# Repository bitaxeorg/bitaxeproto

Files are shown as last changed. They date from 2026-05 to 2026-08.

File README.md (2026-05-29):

bitaxeProto miner with quad Block Proto MC3 ASICs
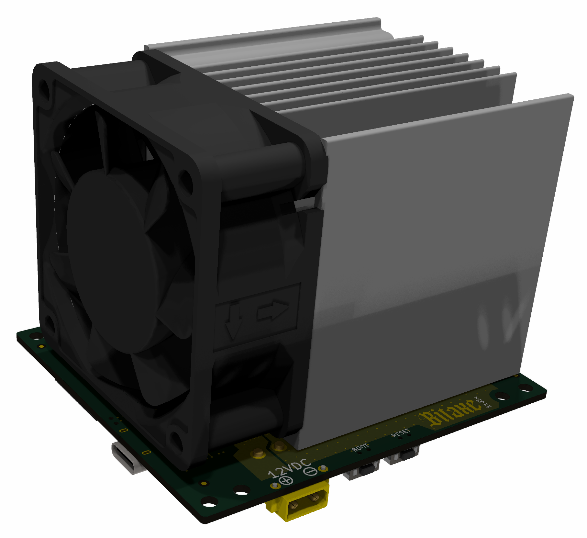
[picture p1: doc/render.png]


It is still an untested prototype! Don't build this expecting it to work yet.

- [Open Hardware License](LICENSE); Real Open Source.
	- [KiCAD](https://kicad.org) design files. 
- Four Proto MC3 ASICs, two stacks of two ASICs
	- Each MC3 is nominally 1.12V with approx 675 GH/s.
- 11-13V XT30 input voltage
- TPS546D24S single-phase voltage regulator tuned for 2.4V output @ 30A
	- The voltage regulator backside power plane is exposed to hopefully thermally bond it with the main heatsink.
- TPS546D24 backside busbar to cool the voltage regulator from the main heatsink.
- Fan controlled from the ESP32
- ESP32S3 for [esp-miner](https://github.com/bitaxeorg/esp-miner) support.
- Display moved off the main board. Should support the [bonanzaDisplay](https://github.com/bitaxeorg/bonanzadisplay)
- Gerbers _not_ provided to discourage side hacks and AliEx slop. HMU if you need help generating gerbers with KiCad.

©️ [bitaxeorg](https://bitaxe.org)

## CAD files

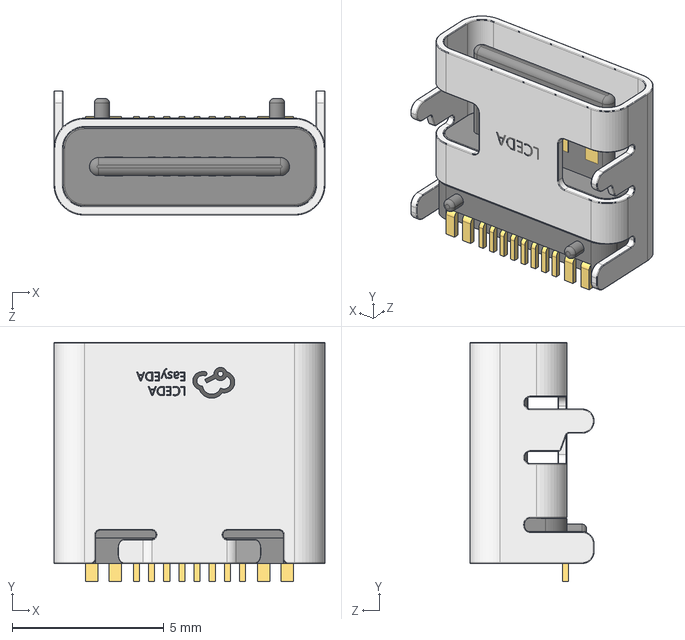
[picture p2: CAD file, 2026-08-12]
3d/USB-C_SMD-TYPE-C-31-M-12_1.step
8.94 x 7.90 x 4.10 mm

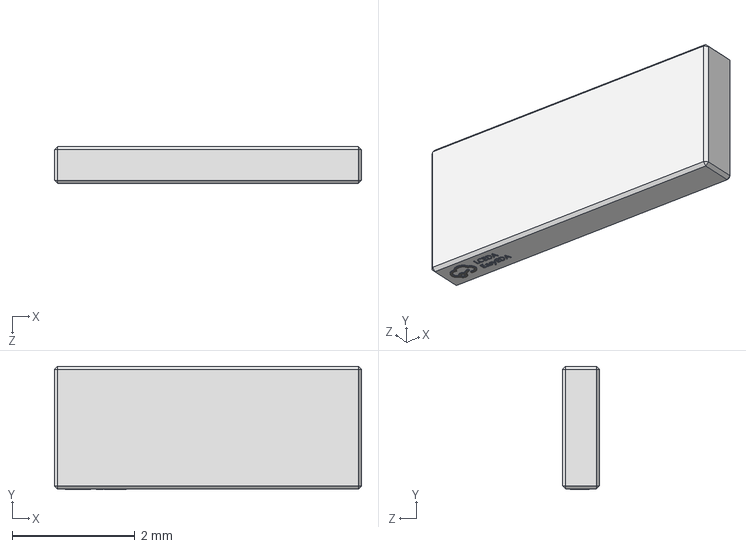
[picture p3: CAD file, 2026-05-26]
3dshapes/PAD-SMD_L5.0-W2.0_STHW4-DU-HN050206.step
5.00 x 2.01 x 0.6 mm

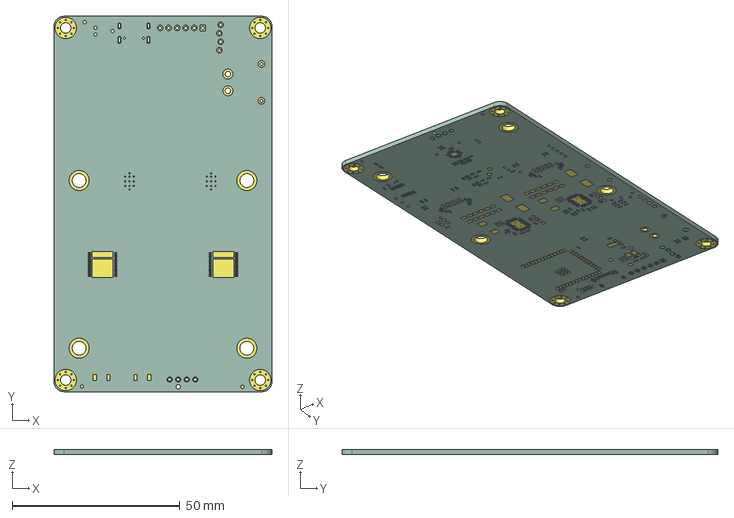
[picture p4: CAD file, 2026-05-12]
bitaxeProto.step
65.0 x 112.0 x 1.59 mm
BitaxeGT_pad
BitaxeGT_PCB

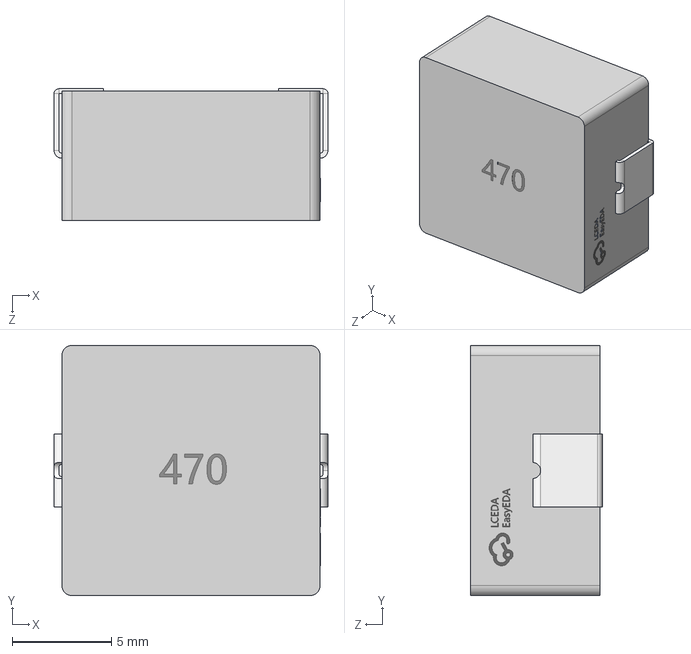
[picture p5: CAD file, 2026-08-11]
3d/IND-SMD_L13.8-W12.6-H6.5.step
13.8 x 12.6 x 6.63 mm

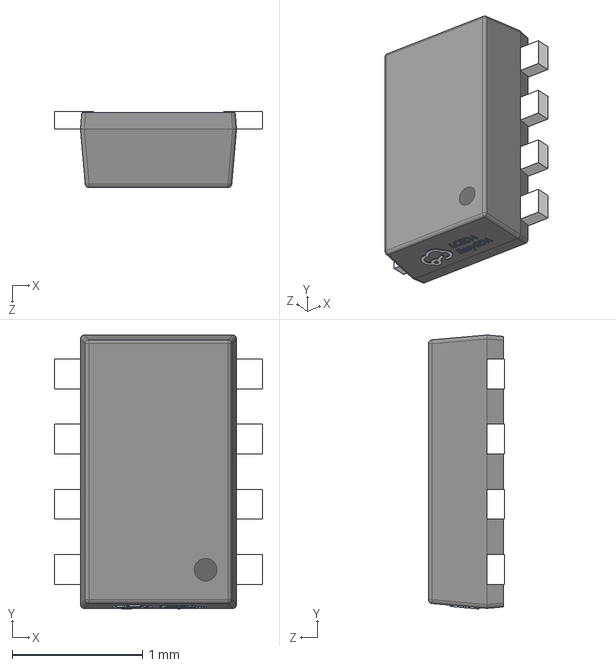
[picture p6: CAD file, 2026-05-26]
3dshapes/SOT-583-8_L2.1-W1.2-P0.50-LS1.6-BR.step
1.60 x 2.10 x 0.585 mm

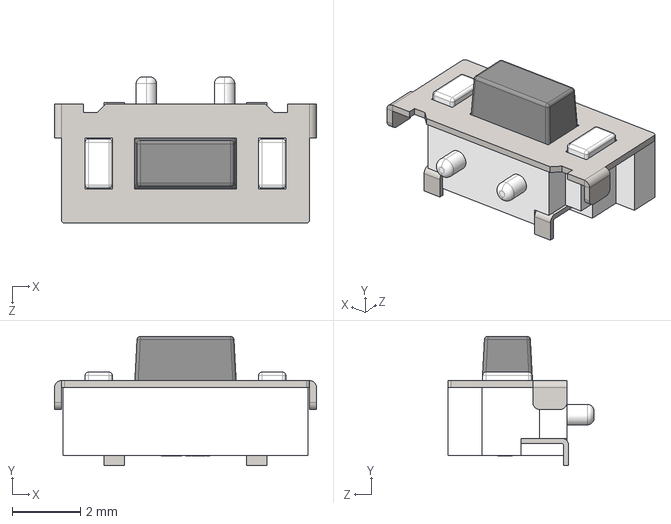
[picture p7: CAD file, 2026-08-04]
3d/SW-SMD_TC-S3601-3.5-260G-F0.6.step
7.70 x 3.80 x 4.30 mm

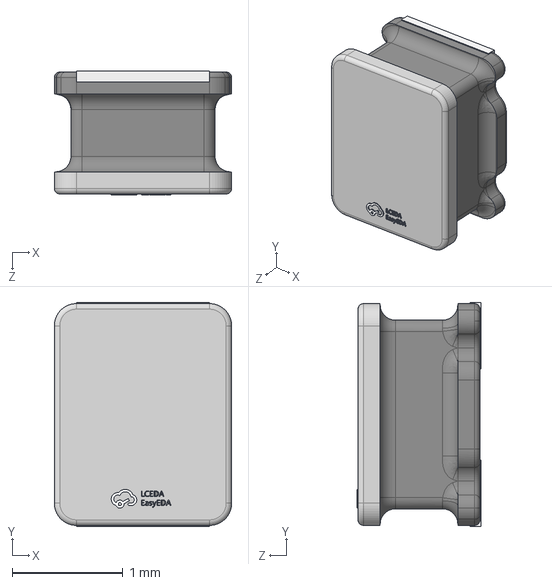
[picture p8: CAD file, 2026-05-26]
3dshapes/IND-SMD_L2.0-W1.6-H1.1.step
1.60 x 2.02 x 1.12 mm

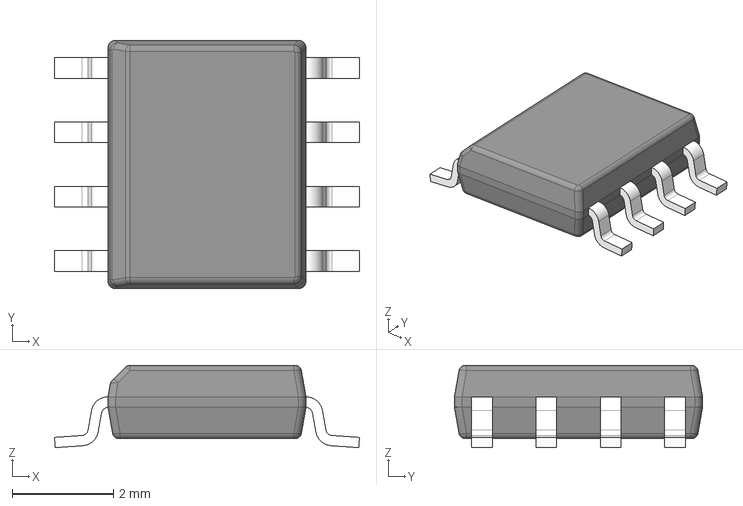
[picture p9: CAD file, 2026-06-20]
3d/D0008A.stp
6.02 x 4.90 x 1.63 mm
BODY-SO
LEAD-D0008A x 8

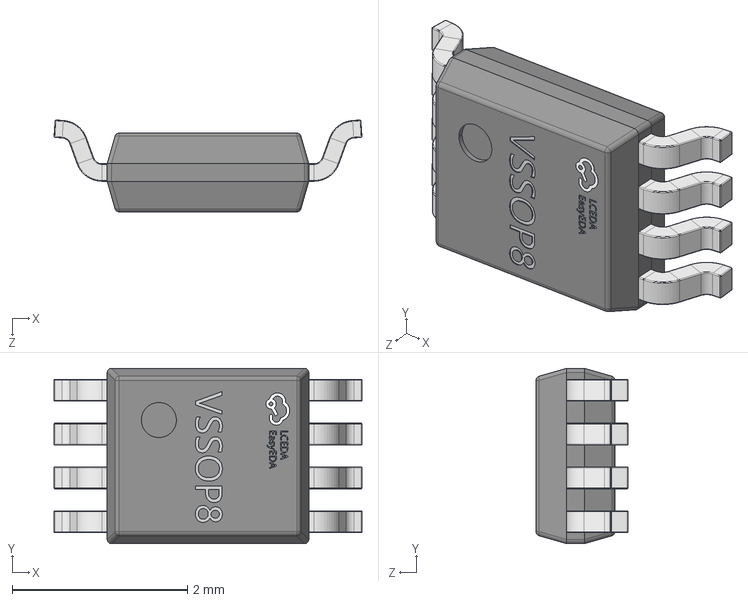
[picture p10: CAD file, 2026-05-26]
3dshapes/VSSOP-8_L2.0-W2.3-H0.9-LS3.1-P0.50.step
3.51 x 2.00 x 1.05 mm

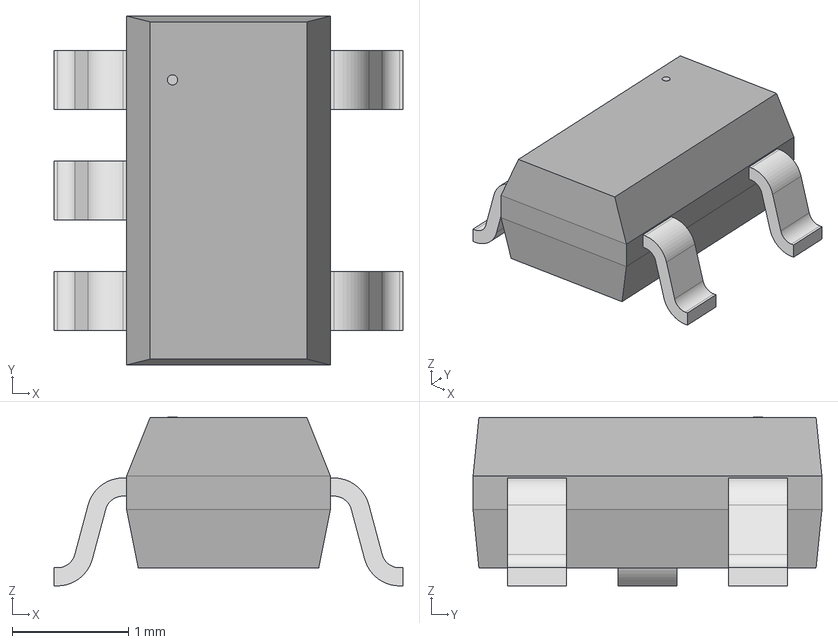
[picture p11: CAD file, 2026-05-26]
3d/SOT23-5_STM.step
3.00 x 3.00 x 1.45 mm

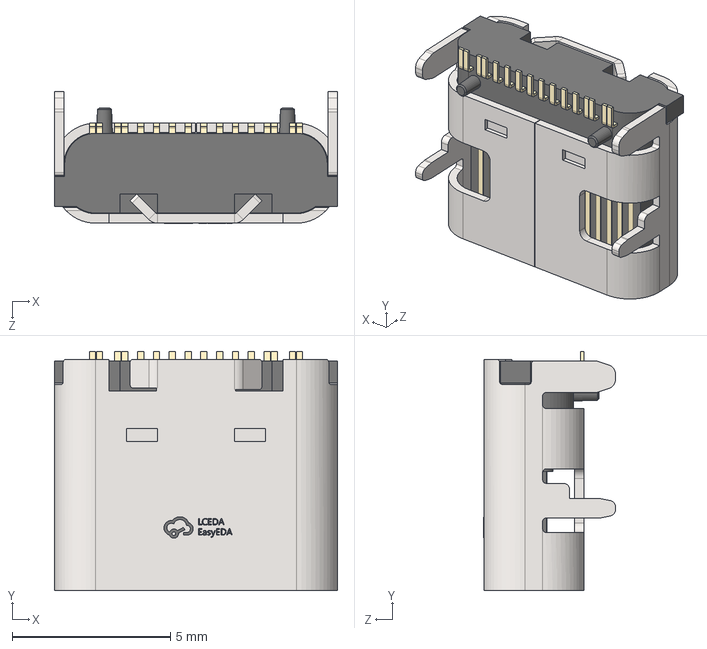
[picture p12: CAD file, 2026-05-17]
3dshapes/TYPE-C-SMD_SBC-160S1A-20-S412.step
8.94 x 7.55 x 4.17 mm

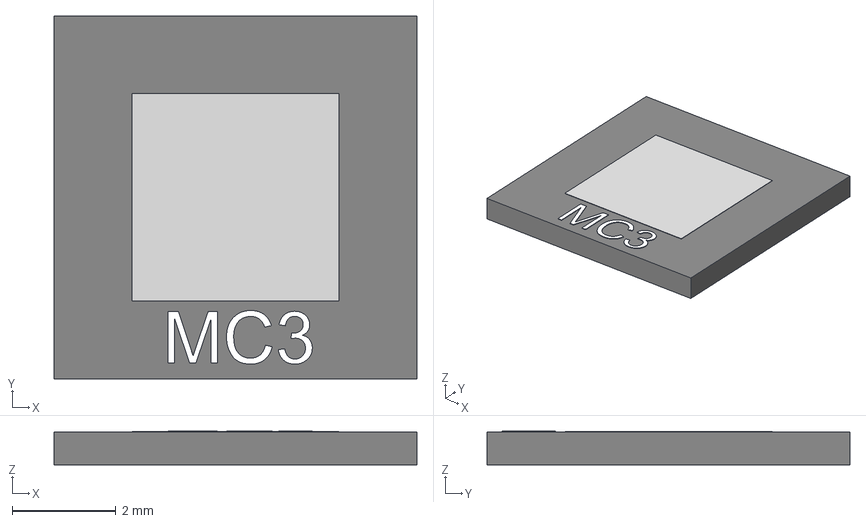
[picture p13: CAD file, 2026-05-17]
3d/mc3_model.step
7.00 x 7.00 x 0.655 mm

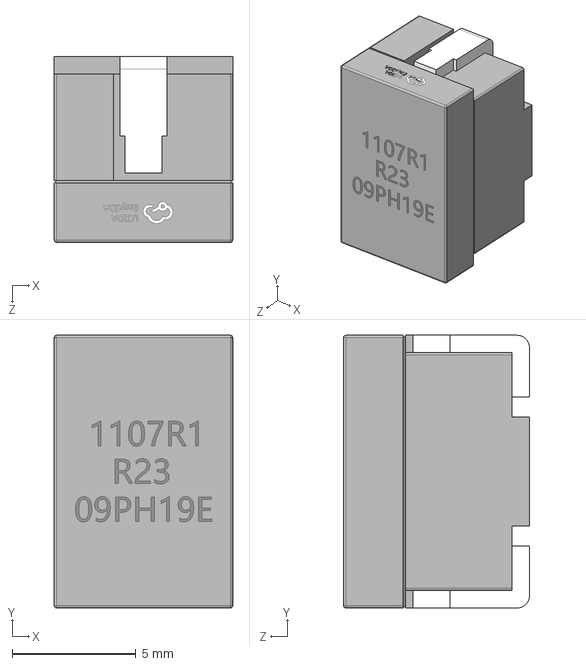
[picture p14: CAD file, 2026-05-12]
3dshapes/IND-SMD_L11.0-W7.2-H7.5.step
7.20 x 11.0 x 7.50 mm

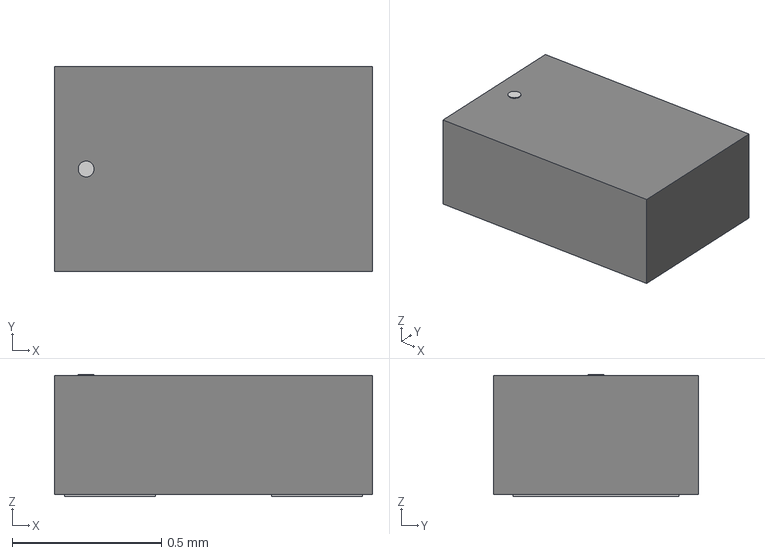
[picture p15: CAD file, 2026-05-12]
3d/DIODE_DLLFSD01LPH4-7B_DIO.step
1.07 x 0.686 x 0.409 mm

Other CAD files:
3d/DISST7789-176x320.STEP
3d/TXB0104RGYR.STEP
3d/ESP32-S3-WROOM-1-N8R2--3DModel-STEP-56544.STEP
3d/141_TL3330AFxxxQG.stp
3d/21-0164B_L622-1_MXM.step
3d/2R5TPE220MAFB.step
3d/470531000.stp
3d/54-00164.STEP
3d/BM04B-SRSS-TB.STEP
3d/BM1368xx.stp
3d/BQB0016A.stp
3d/BZM2.step
3d/BZM2model.step
3d/BitaxeGT_heatsink.step
3d/Bitaxe_Heatsink.step
3d/CS1213AG-tr.stp
3d/CUI_DEVICES_PJ-002AH.step
3d/CUI_DEVICES_PJ-036AH-SMT-TR.step
3d/CUI_DEVICES_PJ-037AH.step
3d/CX3225SB16000H0FLJCC.STEP
3d/Coilcraft-SLC1175.STEP
3d/Coilcraft-XAL1060.STEP
3d/Cree_PLCC6.stp
3d/Crystal_3225.step
3d/DCK0006A.stp
3d/DHVQFN14_SOT762-1_NEX.step
3d/DQG0008A.stp
3d/DQH0008A.stp
3d/DQN0004A.stp
3d/DRC0010J.stp
3d/DRL0006A.stp
3d/ECS-3225MV-500-CN-TR.STEP
3d/FFC2B35-08-T.STEP
3d/FP1006V2-R.STEP
3d/FPC-SMD_P0.50-8P_FGS-XJ-H2.0.step
3d/FTSH-105-01-F-DV-K.stp
3d/Fan 60x60x25mm.stp
3d/GT heatsink.step
3d/IHLP2020CZ.step
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

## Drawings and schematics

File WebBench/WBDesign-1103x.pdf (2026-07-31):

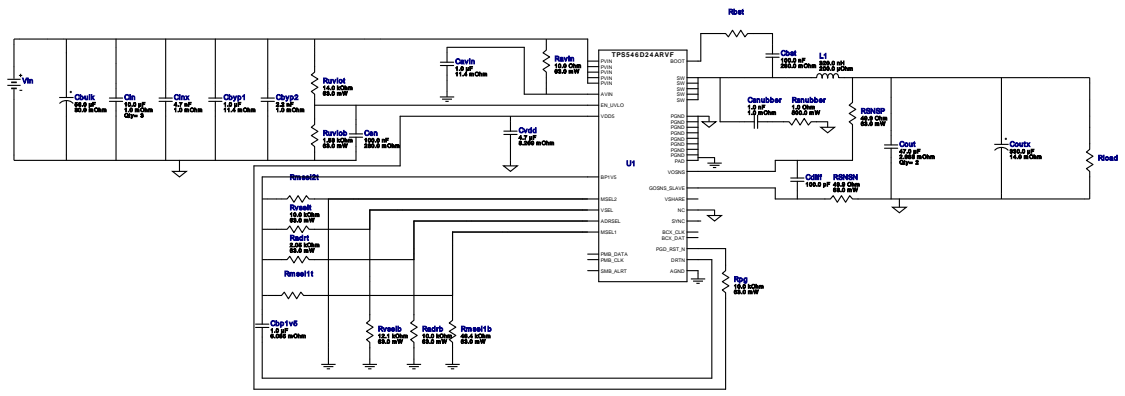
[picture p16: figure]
Cbyp2 2.2 nF 1.0 m Ohm; Cen 100.0 nF 280.0 m Ohm; Rsnubber 1.0 Ohm; Ruvlob 1.58 kOhm 63.0 m W; Cdiff 100.0 pF; Cavin 1.0 µF 11.4 m Ohm Ruvlot 14.0 kOhm; Coutx 330.0 µF 14.0 m Ohm; Cin 10.0 µF 1.0 m Ohm Qty= 3; RSNSN 49.9 Ohm 63.0 m W; Cout 47.0 µF; 2.988 m Ohm Qty= 2; RSNSP 49.9 Ohm 63.0 m W; Cinx 4.7 nF 1.0 m Ohm; Cbp1v5 1.0 µF 6.065 m Ohm; Cbyp1 1.0 µF 11.4 m Ohm; Rvselb 12.1 kOhm 63.0 m W; Rbst; Rpg 10.0 kOhm 63.0 m W; Ravin 10.0 Ohm 63.0 m W; Radrt 2.05 kOhm; Rm sel2t; Rvselt 10.0 kOhm; L1 320.0 nH 200.0 µOhm; Csnubber 1.0 nF; 1.0 m Ohm; Cbulk 56.0 µF 30.0 m Ohm; Cvdd 4.7 µF 8.209 m Ohm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

Copyright © 2026, Texas Instruments Incorporated | 1 | ti.com/webench

WEBENCH®
Design Report TPS546D24ARVFR : TPS546D24ARVFR 11V-13V to 2.20V @ 30A July 31, 2026 15:56:20 GMT-05:00

## WEBENCH ® Design Report

Design : 135 TPS546D24ARVFR
TPS546D24ARVFR 11V-13V to 2.20V @ 30A

VinMin = 11.0V
VinMax = 13.0V
Vout = 2.2V
Vout Sch = 2.2V
Iout = 30.0A

Device = TPS546D24ARVFR
Topology = Buck
Created = 2025-09-15 13:40:46.376 BOM Cost = $8.80
BOM Count = 31
Total Pd = 4.64W
1. Do not place Rmsel2t, Rmsel1t resistors. Place 0 Ohm resistor for Rbst.

### Design Alerts

TPS546D24A Design
The TPS546D24A is a PMBus(TM) device with key features listed below: PMBus(TM) features marked with * are included in WEBENCH(R) Power Designer. - Adaptive Voltage Scaling (AVS) through VOUT_COMMAND*, - Output voltage and current monitoring, - Thermal Shutdown,
- Programmable over current protection, - OCP,OV, UV, OT Levels, - Selectable Internal Compensation*, - Selectable Switching Frequency*,
- Turn-On and Turn-Off Delays, - UVLO*, Soft-Start*,OCP* and Soft-Stop. Use the Advanced Options on the left side to set the PMBus(TM) commands. Please refer to the TPS546D24A datasheet and visit http://www.ti.com/pmbus for more information.

## Electrical BOM

Name | Manufacturer | Part Number | Properties | Qty Price | Footprint
Cavin | TDK | C1005X5R1E105K050BC (https://product.tdk.com/ja/search/capacitor/ceramic/mlcc/info?part%5Fno%3DC1005X5R1E105K050BC) Series= X5R | Cap= 1.0 uF ESR= 11.4 mOhm VDC= 25.0 V IRMS= 0.0 A
1 | $0.02
| | | | | 0402 3 mm²
Cbp1v5 | MuRata | GRM188R60J105KA01D (http://psearch.en.murata.com/capacitor/result/smd/?status%3Dall%26pid%3DGRM188R60J105KA01D) Series= X5R

Cap= 1.0 uF
ESR= 6.065 mOhm
VDC= 6.3 V
IRMS= 1.36934 A

1 $0.01
0603 5 mm²
Cbst | AVX | 08053C104KAT2A (http://datasheets.avx.com/X7RDielectric.pdf) Series= X7R

Cap= 100.0 nF
ESR= 280.0 mOhm
VDC= 25.0 V
IRMS= 0.0 A

1 $0.01
0805 7 mm²

Design

Copyright © 2026, Texas Instruments Incorporated | 2 | ti.com/webench
Name | Manufacturer | Part Number | Properties | Qty Price | Footprint
Cbulk | Panasonic | 20SVPF56MX Series= SVPF | Cap= 56.0 uF ESR= 30.0 mOhm VDC= 20.0 V IRMS= 2.8 A
1 | $0.47
| | | | | CAPSMT_62_E61 53 mm²
Cbyp1 | TDK | C1005X5R1E105K050BC (https://product.tdk.com/ja/search/capacitor/ceramic/mlcc/info?part%5Fno%3DC1005X5R1E105K050BC) Series= X5R | Cap= 1.0 uF ESR= 11.4 mOhm VDC= 25.0 V IRMS= 0.0 A
1 | $0.02
| | | | | 0402 3 mm²
Cbyp2 | MuRata | GRM155R61E222KA01D (http://search.murata.co.jp/Ceramy/PnsearchViewAction.do) Series= X5R

Cap= 2.2 nF
ESR= 1.0 mOhm
VDC= 25.0 V
IRMS= 0.0 A

1 $0.01
0402 3 mm²
Cdiff | Yageo | CC0201JRNPO8BN101 (http://www.yageo.com/documents/recent/UPY%2DGP%5FNP0%5F16V%2Dto%2D50V%5F10.pdf) Series= C0G/NP0

Cap= 100.0 pF
VDC= 5.0 V
IRMS= 0.0 A

1 $0.01
0201 2 mm²
Cen | AVX | 08053C104KAT2A (http://datasheets.avx.com/X7RDielectric.pdf) Series= X7R

Cap= 100.0 nF
ESR= 280.0 mOhm
VDC= 25.0 V
IRMS= 0.0 A

1 $0.01
0805 7 mm²
Cin | TDK | C3225X7R1H106M250AC Series= X7R

Cap= 10.0 uF
ESR= 1.0 mOhm
VDC= 50.0 V
IRMS= 5.0 A

3 $0.27
1210 15 mm²
Cinx | MuRata | GRM155R71E472KA01D (http://search.murata.co.jp/Ceramy/PnsearchViewAction.do) Series= X7R

Cap= 4.7 nF
ESR= 1.0 mOhm
VDC= 25.0 V
IRMS= 0.0 A

1 $0.01
0402 3 mm²
Cout | Taiyo Yuden | MSASJ21GBB5476MTNA01 (https://ds.yuden.co.jp/TYCOMPAS/ut/detail?pn%3DMSASJ21GBB5476MTNA01%26u%3DM) Series= X5R

Cap= 47.0 uF
ESR= 2.988 mOhm
VDC= 6.3 V
IRMS= 3.5841 A

2 $0.09
0805 7 mm²
Coutx | Chemi-Con | APXE6R3ARA331MF80G (http://www.chemi%2Dcon.co.jp/cgi%2Dbin/CAT%5FDB/SEARCH/cat%5Fdb%5Fal.cgi?e%3De%26j%3Dp%26pdfname%3Dpxe) Series= PXE

Cap= 330.0 uF
ESR= 14.0 mOhm
VDC= 6.3 V
IRMS= 3.47 A

1 $0.93

CAPSMT_62_F80 74 mm²
Csnubber Yageo | CC0805KRX7R9BB102 (http://www.yageo.com/documents/recent/UPY%2DGPHC%5FX7R%5F6.3V%2Dto%2D50V%5F7.pdf)
| | Series= X7R
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

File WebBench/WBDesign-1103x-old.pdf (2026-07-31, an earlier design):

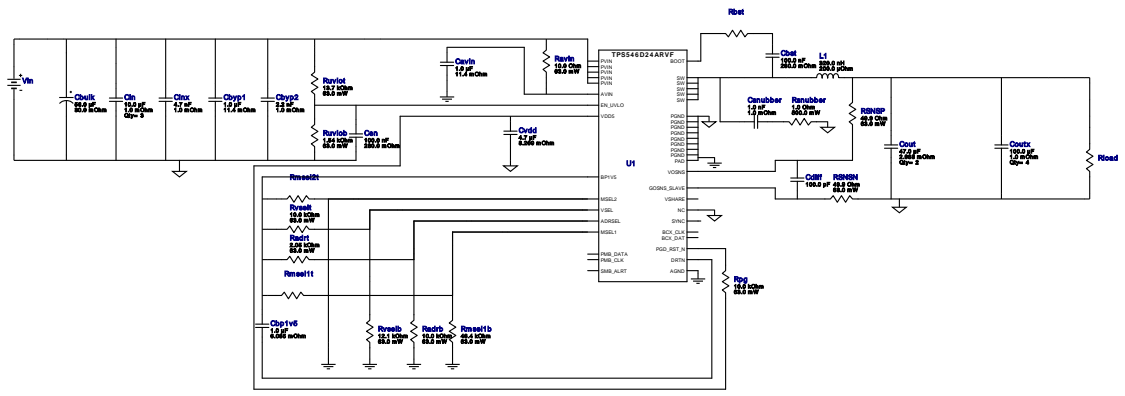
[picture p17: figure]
Cbyp2 2.2 nF 1.0 m Ohm; Cen 100.0 nF 280.0 m Ohm; Rsnubber 1.0 Ohm; Ruvlob 1.54 kOhm 63.0 m W; Cdiff 100.0 pF; Cavin 1.0 µF 11.4 m Ohm Ruvlot 13.7 kOhm; Coutx 100.0 µF 1.0 m Ohm Qty= 4; Cin 10.0 µF 1.0 m Ohm Qty= 3; RSNSN 49.9 Ohm 63.0 m W; Cout 47.0 µF; 2.988 m Ohm Qty= 2; RSNSP 49.9 Ohm 63.0 m W; Cinx 4.7 nF 1.0 m Ohm; Cbp1v5 1.0 µF 6.065 m Ohm; Cbyp1 1.0 µF 11.4 m Ohm; Rvselb 12.1 kOhm 63.0 m W; Rbst; Rpg 10.0 kOhm 63.0 m W; Ravin 10.0 Ohm 63.0 m W; Radrt 2.05 kOhm; Rm sel2t; Rvselt 10.0 kOhm; L1 320.0 nH 200.0 µOhm; Csnubber 1.0 nF; 1.0 m Ohm; Cbulk 56.0 µF 30.0 m Ohm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

Copyright © 2026, Texas Instruments Incorporated | 1 | ti.com/webench

WEBENCH®
Design Report TPS546D24ARVFR : TPS546D24ARVFR 11V-13V to 2.20V @ 30A July 20, 2026 19:36:30 GMT-05:00

## WEBENCH ® Design Report

Design : 134 TPS546D24ARVFR
TPS546D24ARVFR 11V-13V to 2.20V @ 30A

VinMin = 11.0V
VinMax = 13.0V
Vout = 2.2V
Vout Sch = 2.2V
Iout = 30.0A

Device = TPS546D24ARVFR
Topology = Buck
Created = 2025-09-15 13:40:46.376 BOM Cost = $8.55
BOM Count = 34
Total Pd = 4.63W
1. Do not place Rmsel2t, Rmsel1t resistors. Place 0 Ohm resistor for Rbst.

### Design Alerts

TPS546D24A Design
The TPS546D24A is a PMBus(TM) device with key features listed below: PMBus(TM) features marked with * are included in WEBENCH(R) Power Designer. - Adaptive Voltage Scaling (AVS) through VOUT_COMMAND*, - Output voltage and current monitoring, - Thermal Shutdown,
- Programmable over current protection, - OCP,OV, UV, OT Levels, - Selectable Internal Compensation*, - Selectable Switching Frequency*,
- Turn-On and Turn-Off Delays, - UVLO*, Soft-Start*,OCP* and Soft-Stop. Use the Advanced Options on the left side to set the PMBus(TM) commands. Please refer to the TPS546D24A datasheet and visit http://www.ti.com/pmbus for more information.

## Electrical BOM

Name | Manufacturer | Part Number | Properties | Qty Price | Footprint
Cavin | TDK | C1005X5R1E105K050BC (https://product.tdk.com/ja/search/capacitor/ceramic/mlcc/info?part%5Fno%3DC1005X5R1E105K050BC) Series= X5R | Cap= 1.0 uF ESR= 11.4 mOhm VDC= 25.0 V IRMS= 0.0 A
1 | $0.02
| | | | | 0402 3 mm²
Cbp1v5 | MuRata | GRM188R60J105KA01D (http://psearch.en.murata.com/capacitor/result/smd/?status%3Dall%26pid%3DGRM188R60J105KA01D) Series= X5R

Cap= 1.0 uF
ESR= 6.065 mOhm
VDC= 6.3 V
IRMS= 1.36934 A

1 $0.01
0603 5 mm²
Cbst | AVX | 08053C104KAT2A (http://datasheets.avx.com/X7RDielectric.pdf) Series= X7R

Cap= 100.0 nF
ESR= 280.0 mOhm
VDC= 25.0 V
IRMS= 0.0 A

1 $0.01
0805 7 mm²

Design

Copyright © 2026, Texas Instruments Incorporated | 2 | ti.com/webench
Name | Manufacturer | Part Number | Properties | Qty Price | Footprint
Cbulk | Panasonic | 20SVPF56MX Series= SVPF | Cap= 56.0 uF ESR= 30.0 mOhm VDC= 20.0 V IRMS= 2.8 A
1 | $0.47
| | | | | CAPSMT_62_E61 53 mm²
Cbyp1 | TDK | C1005X5R1E105K050BC (https://product.tdk.com/ja/search/capacitor/ceramic/mlcc/info?part%5Fno%3DC1005X5R1E105K050BC) Series= X5R | Cap= 1.0 uF ESR= 11.4 mOhm VDC= 25.0 V IRMS= 0.0 A
1 | $0.02
| | | | | 0402 3 mm²
Cbyp2 | MuRata | GRM155R61E222KA01D (http://search.murata.co.jp/Ceramy/PnsearchViewAction.do) Series= X5R

Cap= 2.2 nF
ESR= 1.0 mOhm
VDC= 25.0 V
IRMS= 0.0 A

1 $0.01
0402 3 mm²
Cdiff | Yageo | CC0201JRNPO8BN101 (http://www.yageo.com/documents/recent/UPY%2DGP%5FNP0%5F16V%2Dto%2D50V%5F10.pdf) Series= C0G/NP0

Cap= 100.0 pF
VDC= 5.0 V
IRMS= 0.0 A

1 $0.01
0201 2 mm²
Cen | AVX | 08053C104KAT2A (http://datasheets.avx.com/X7RDielectric.pdf) Series= X7R

Cap= 100.0 nF
ESR= 280.0 mOhm
VDC= 25.0 V
IRMS= 0.0 A

1 $0.01
0805 7 mm²
Cin | TDK | C3225X7R1H106M250AC Series= X7R

Cap= 10.0 uF
ESR= 1.0 mOhm
VDC= 50.0 V
IRMS= 5.0 A

3 $0.27
1210 15 mm²
Cinx | MuRata | GRM155R71E472KA01D (http://search.murata.co.jp/Ceramy/PnsearchViewAction.do) Series= X7R

Cap= 4.7 nF
ESR= 1.0 mOhm
VDC= 25.0 V
IRMS= 0.0 A

1 $0.01
0402 3 mm²
Cout | Taiyo Yuden | MSASJ21GBB5476MTNA01 (https://ds.yuden.co.jp/TYCOMPAS/ut/detail?pn%3DMSASJ21GBB5476MTNA01%26u%3DM) Series= X5R

Cap= 47.0 uF
ESR= 2.988 mOhm
VDC= 6.3 V
IRMS= 3.5841 A

2 $0.09
0805 7 mm²
Coutx | MuRata | GRM32EC80J107ME20L Series= X6S

Cap= 100.0 uF
ESR= 1.0 mOhm
VDC= 6.3 V
IRMS= 6.0 A

4 $0.17
1210_270 15 mm²
Csnubber Yageo | CC0805KRX7R9BB102 (http://www.yageo.com/documents/recent/UPY%2DGPHC%5FX7R%5F6.3V%2Dto%2D50V%5F7.pdf)
| | Series= X7R

Cap= 1.0 nF
ESR= 1.0 mOhm
VDC= 50.0 V
IRMS= 0.0 A
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

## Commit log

2026-05-12 initial import - moving bitaxeBlock onto bitaxeBonanza platform and renaming bitaxeProto-1102x
    [141_TL3330AFxxxQG.stp, 21-0164B_L622-1_MXM.step, 2R5TPE220MAFB.step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]
2026-05-12 move over to bitaxeBlock ASIC sheet
    [ASIC.kicad_sch, level_shifter.kicad_sch]
2026-05-12 switch aux voltage regulators to TPS62933
    [Power.kicad_sch, bitaxeProto-1102x.kicad_sch, data.kicad_sch]
2026-05-12 remove 1102x from filenames
    [ASIC.kicad_sch, IND-SMD_L11.0-W7.2-H7.5.step, Power.kicad_sch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]
2026-05-17 add footprints and some 3d cad. rough part placements
    [ASIC.kicad_sch, Power.kicad_sch, TYPE-C-SMD_SBC-160S1A-20-S412.step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]
2026-05-18 a lot more rough component placement
    [ASIC.kicad_sch, bitaxeProto.kicad_pcb]
2026-05-18 power plane tweaking
    [bitaxeProto.kicad_pcb]
2026-05-26 routing progress
    [ASIC.kicad_sch, IND-SMD_L2.0-W1.6-H1.1.step, PAD-SMD_L5.0-W2.0_STHW4-DU-HN050206.step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]
2026-05-26 remove old bzm2 stuff
    [ASIC.kicad_sch, bitaxeProto.kicad_pcb]
2026-05-26 lots of signal routing
    [bitaxeProto.kicad_pcb]
2026-05-28 lots of DRC fixes. adding power plane via grid.
    [Power.kicad_sch, bitaxeProto.kicad_pcb, data.kicad_sch]
2026-05-28 add more data test points. Fix ERC & DRC issues
    [ASIC.kicad_sch, Power.kicad_sch, bitaxeProto.kicad_pcb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]
2026-05-28 update schematic BOM and some part substitutions
    [ASIC.kicad_sch, Power.kicad_sch, bitaxeProto.kicad_pcb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]
2026-05-29 switched to larger LDOs. 0.75V -> 0.8V. Tweaked power planes some more
    [ASIC.kicad_sch, bitaxeProto.kicad_pcb, data.kicad_sch]
2026-05-29 update readme and render
    [bitaxeProto.kicad_pcb]
2026-05-29 fix display connector orientation
    [bitaxeProto.kicad_pcb, data.kicad_sch]
2026-05-29 condense symbol libraries into just bitaxe library
    [Power.kicad_sch, data.kicad_sch]
2026-05-29 pcb touchup after gerber review
    [Power.kicad_sch, bitaxeProto.kicad_pcb]
2026-06-20 update U19 footprint for #1. fix TP silkscreen orientation
    [D0008A.stp, Power.kicad_sch, bitaxeProto.kicad_pcb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]
2026-06-20 update all versions to 1102xx
    [ASIC.kicad_sch, Power.kicad_sch, bitaxeProto.kicad_pcb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]
2026-07-31 fix TPS546 frequency for #4 - fix SN74AVC2T45 level shifter DIR voltage for #2
    [ASIC.kicad_sch, Power.kicad_sch, bitaxeProto.kicad_pcb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]
2026-07-31 add domain voltage sensing for #3 -- just schematic so far
    [ASIC.kicad_sch, bitaxeProto.kicad_pcb, bitaxeProto.kicad_sch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]
2026-07-31 update PCB to 1103x
    [bitaxeProto.kicad_pcb]
2026-08-01 new smaller board outline. repositioned a lot of components
    [bitaxeProto.kicad_pcb, bitaxeProto.kicad_sch, data.kicad_sch]
2026-08-04 switched to 12pin display header. routed SWD to display header. finished preliminary board routing.
    [Power.kicad_sch, bitaxeProto.kicad_pcb, data.kicad_sch]
2026-08-04 cleaned up some traces, repositioned logo
    [bitaxeProto.kicad_pcb]
2026-08-04 fix button 3d models
    [SW-SMD_TC-S3601-3.5-260G-F0.6.step, bitaxeProto.kicad_pcb]
2026-08-09 changed fan connector footprint back to normal. lots of part substitutions for JLCPCB. Mounting hole changes for enclosure
    [ASIC.kicad_sch, Power.kicad_sch, bitaxeProto.kicad_pcb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]
2026-08-09 re-added many missing LCSC part numbers that got lost in translation
    [ASIC.kicad_sch, Power.kicad_sch, bitaxeProto.kicad_pcb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]
2026-08-11 DRC fixes. added filled via notes. power track tweaking. switched fan connecter back to normal (again)
    [ASIC.kicad_sch, Power.kicad_sch, bitaxeProto.kicad_pcb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]
2026-08-11 found a C4 JLCPCB part sub.
    [Power.kicad_sch, bitaxeProto.kicad_pcb]
2026-08-11 silkscreen cleanup and render update
    [bitaxeProto.kicad_pcb]
2026-08-11 switch L1 to MS1350-R36M for this run as the SLC1480-321 is 100% out of stock.
    [IND-SMD_L13.8-W12.6-H6.5.step, Power.kicad_sch, bitaxeProto.kicad_pcb]
2026-08-11 updated stale resistor values. changed C29/C30 to 0603 footprints to match LCSC basic
    [Power.kicad_sch, bitaxeProto.kicad_pcb]
2026-08-12 switch to cheaper USB-C connector
    [ASIC.kicad_sch, Power.kicad_sch, Supply.kicad_sch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]
2026-08-12 updated part values for 3 components to match actual
    [ASIC.kicad_sch, bitaxeProto.kicad_pcb, data.kicad_sch]
2026-08-12 updated part attributes for JLCPCB Fabrication Toolkit
    [ASIC.kicad_sch, Power.kicad_sch, bitaxeProto.kicad_pcb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]
2026-09-04 add ASIC esp-miner numbers comment. exclude production files
    [ASIC.kicad_sch, TPS546x24A_Compensation_Pinstrap_Calculator_Release20200120.xlsx]

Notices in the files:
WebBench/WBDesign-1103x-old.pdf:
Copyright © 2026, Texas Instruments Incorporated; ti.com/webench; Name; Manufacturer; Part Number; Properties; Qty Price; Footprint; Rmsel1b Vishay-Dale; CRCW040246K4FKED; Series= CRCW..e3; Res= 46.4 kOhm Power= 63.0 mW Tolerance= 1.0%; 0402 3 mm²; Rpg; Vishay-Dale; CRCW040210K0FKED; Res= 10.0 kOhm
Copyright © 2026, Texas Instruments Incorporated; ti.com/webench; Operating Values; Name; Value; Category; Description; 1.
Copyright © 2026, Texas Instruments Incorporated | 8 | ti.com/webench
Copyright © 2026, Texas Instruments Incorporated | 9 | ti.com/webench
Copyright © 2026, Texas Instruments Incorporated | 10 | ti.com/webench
